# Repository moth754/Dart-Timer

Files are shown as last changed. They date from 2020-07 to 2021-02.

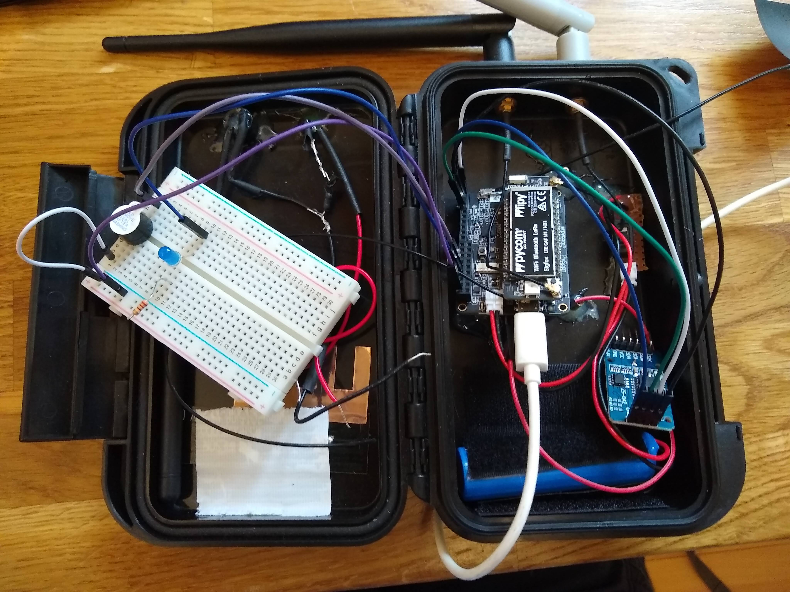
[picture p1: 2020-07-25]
Instructions/Images/Proof of concept.jpg

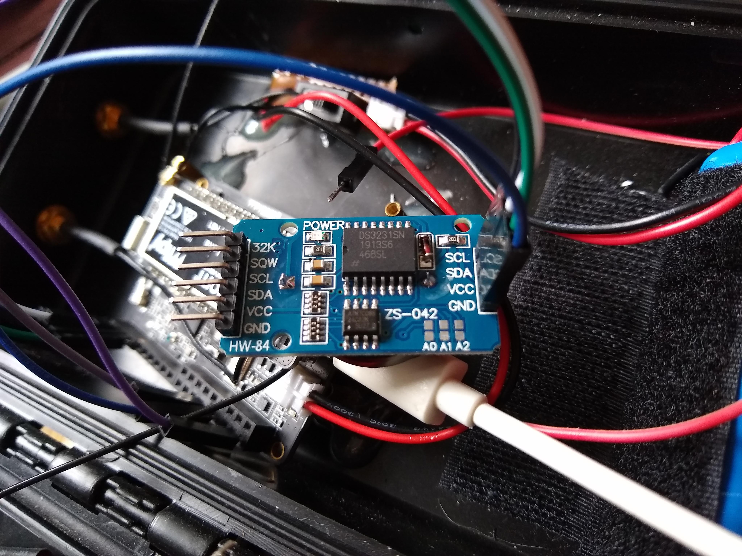
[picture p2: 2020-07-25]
Instructions/Images/RTC.jpg

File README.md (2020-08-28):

# Dart-Timer
This is a timing system built using micropython and based on a [Pycom](https://pycom.io/) FiPy board (will work with some other pycom boards).

The system records taps via NFC chips and relays the chip ID and the time of the tap to a Google Sheet. This can then be analysed to produce timing results.

The system makes use of Pycom's [Pybytes](https://pycom.io/products/software/pybytes-3/) as an easy way to manage the devices and recieve the data. The Pybytes software then sends the data on to the Google Sheet via HTTP post.

Obviously you will need a stock of NFC chips to make this work, but these are freely available - just check it's compatible with a MFRC630. 

Why is this different to other timing systems?
- Others can build, use and develop for free
- Uses Google Sheets so no additional specialist software is required and permissions can be managed easily (so a cut down view can shared with the public live during the race, marshals can see how many are on the course at a glance etc)
- Low running costs (no ongoing license fee for the software or hardware)
- Uses technology such as LoRa and NB-IOT to provide live data even in areas with poor mobile connectivity
- Relatively low cost per checkpoint in comparison to other live data feed systems
- Low cost and re-usable competitor devices (a simple wrist worn NFC tag)

##### Go Fund Me link for the next stage of development - https://gf.me/u/yiimtw

## Important code information
You need to run the following code via REPL to disable pybytes autostart. If you don't do this you will experience slowdowns due to mutliple threads connecting to the network. It will survive reboots.

```python
import pycom
pycom.pybytes_on_boot(False)
```

## Features
### Working and tested
* Records taps by NFC chips to local SD and send to Google Sheet
* Competitor numbers, names distances etc are all held in Google Sheets, so permissions and changes are straight-forward
* Visual and audible indication of successful tap by competitor
* Can use wifi, LoRa ([The Things Network](https://www.thethingsnetwork.org/)) and NB-IOT (a low power, long range cellular network) to connect to the internet
* Device design encloses the entire project in a small waterproof case
* Real time clock which can be updated via NTP via using a particular NFC card (set in code)

### Probably working but needs more testing
* 24 hour battery life
* Devices can mesh network to reduce the chances of connectivity outage - see [Pycom's](https://pycom.io/launching-mesh-networks/) page on mesh networking for more info

### Upcoming
The "to do" list can be found [here](https://trello.com/b/PtuwPh5d/timing-system) on Trello

## Instructions
Build instructions can be found in the instructions folder [here](https://github.com/moth754/Dart-Timer/blob/master/Instructions/INSTRUCTIONS.md).

# The Story
For a couple of years I have marshalled and timed various events. These have mostly been trail running, with a bit of swim running added in for good measure. On the higher risk ultra events timing was done by GPS trackers, but for the rest either NFC (webscorer or SiE) or RFID timing was used.

The most commonly asked question by far when I've been timing events has been by friends and family of the competitors "can you see where they are?" The answer is usually no. Interim timing points require additional kit and extra personnel, both f which are a luxery not normally available for the small to medium scale events. When splits timing is required we often hire the superb SiE system forn another local organiser. Several of our events do have a few splits!

Water safety teams would ask how many in and out the water for different swimrun stages, which the marshals on those checkpoints can usually provide. until they get distracted from counting to deal with first aid issues etc. 

To answer both the issue of people wanting to know where thier loved ones are on a route, and the safety issues, this timing system has come about. On the surface it is a very simple concept. Record who scans it at what time. However, it have taken a year of experimentation (on and off), and near giving up to get this far.

It's available to all (see license) as although it is a fairly technical know how heavy solution, for some race organisers and race timers it may prove useful.

## Thanks
Thanks the the following sources whom I have used thier code (in accordance with licenses) to make this project possible. 

* DS3231 code from the [MicroPython Chinese Community](https://github.com/micropython-Chinese-Community/mpy-lib/tree/master/misc/DS3231)
* This [post](https://railsrescue.com/blog/2015-05-28-step-by-step-setup-to-send-form-data-to-google-sheets/) by Scott Olmsted on posting to Google Sheets
* Pycom support who have been amazing solving problems (largely created by me)
* The PCA9554 library by akael "ported" by theshade
* Everyone elses various posts on forums etc I read in the making of this!

Special thanks to-
 * Laura (https://www.runventureonline.com/)
 * Ceri (https://www.wildrunning.co.uk/)
 * Ben (https://www.lasportiva.com/en)

All three are runners (with running related buisnesses) and have spurred me on to complete this project, even when I was ready to give up.

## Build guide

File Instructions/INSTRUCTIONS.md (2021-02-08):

##This is all going to change - I am switching hardware to use a custom PCB for interconnecting the modules and a Adafruit PN532 NFC reader for increased range. The end product should be significantly more robust.

# Instructions
These are the instructions to build the device how I did. It is possible to modify / change components and still end up with a working result.

## Google Sheets Instuctions
These are based on the instructions found [here](https://railsrescue.com/blog/2015-05-28-step-by-step-setup-to-send-form-data-to-google-sheets/).

1. Start a new sheet and save it in Google Docs. Add the columns names "device" and "payload"
2. Click on Tools - Script Editor
3. Click on File - New Script File
4. Paste in the code from GoogleIntegrations.gs (top level in this repository)
5. Click "Run"
6. Click on Publish - Deploy as web app
7. Make a note of the URL
8. Integration should be set to "Me"
9. Who has access should be set to "Anyone, even anonymous"
10. Click Deploy / Update

## Webhook Instructions
1. Setup a signal as "SIG 1", "taps" in the pybytes signals section
2. Setup a webhook integration under Pybytes integrations section. The correct configuration is shown in the Pybytes Webhook image
3. The URL is the "current web app URL" from the Google Sheets setup

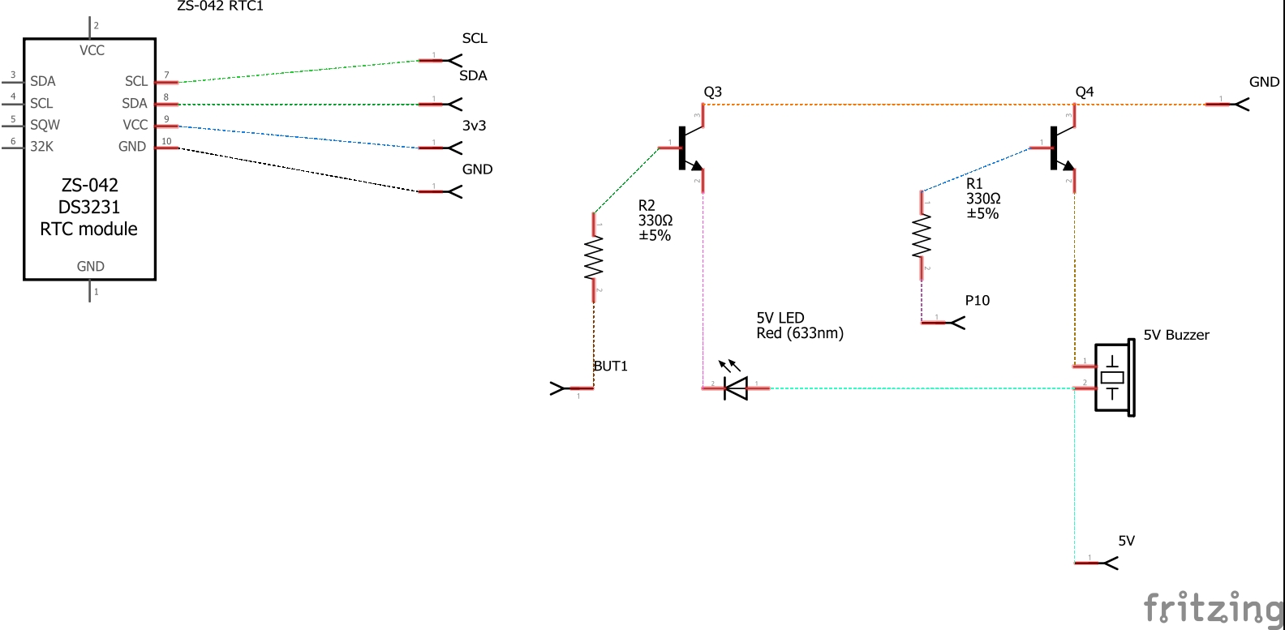
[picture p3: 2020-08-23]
Instructions/Images/Wiring diagram_schem.jpg

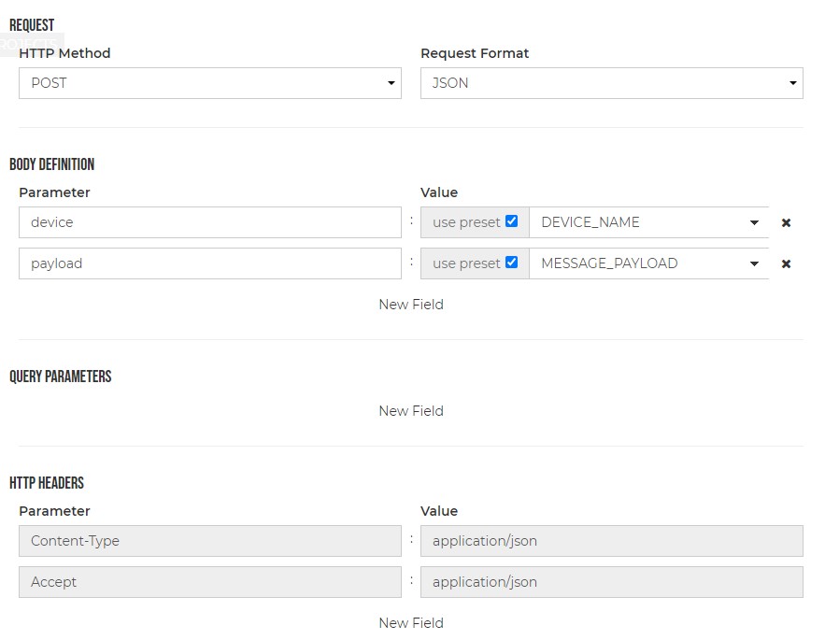
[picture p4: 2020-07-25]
Instructions/Images/Pybytes Webhook.jpg

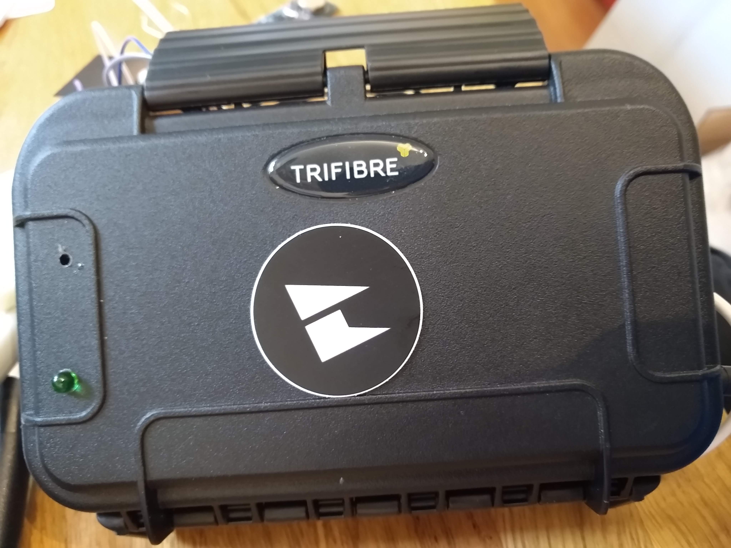
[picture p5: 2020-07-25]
Instructions/Images/Front.jpg

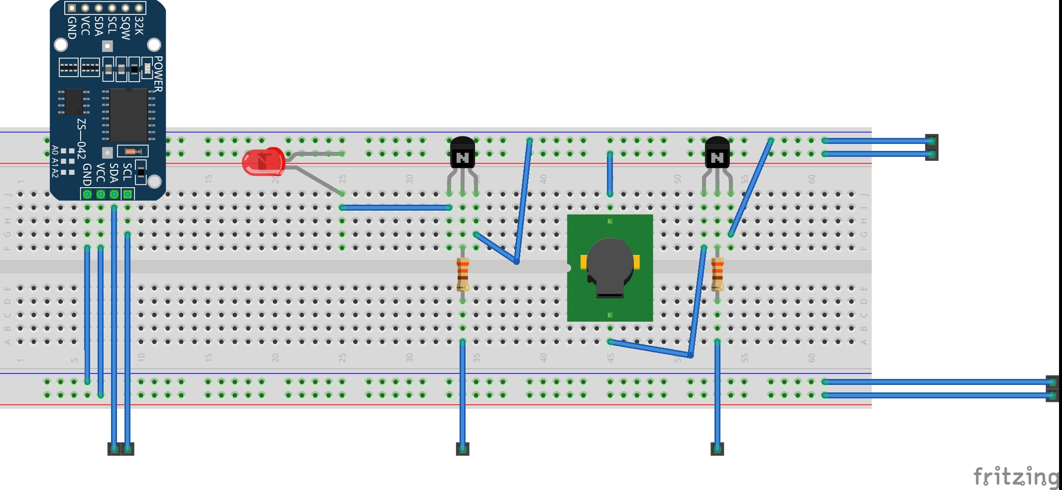
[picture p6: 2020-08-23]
Instructions/Images/Wiring diagram_bb.jpg

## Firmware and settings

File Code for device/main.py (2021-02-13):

################### imports

#print("Starting imports")

from pyscan import Pyscan
from MFRC630 import MFRC630
import time
import pycom
from machine import SD, I2C, RTC, Pin, ADC
from pca9554 import PCA9554 #for io expander
import _thread
import os
import DS3231 #for RTC
import gc
import ubinascii

#imports for pybytes if doing manual on and off or reading
#from _pybytes_config import PybytesConfig
#from _pybytes import Pybytes
#pybytes_config = PybytesConfig().read_config()
#pybytes = Pybytes(pybytes_config)

#import for watchdog
from machine import WDT

#####################setups

#pymesh
pymesh = pybytes.__pymesh.__pymesh
#pymesh.status_str() whole status string - we want character 5

#setup SD card
sd = SD()
os.mount(sd, "/sd")

#setup buzzer using Pin
buzzer = Pin('P11', mode=Pin.OUT)
#tests buzzer using pin
buzzer(True)
time.sleep(1)
buzzer(False)

#setup LEDs using IO expander
led = PCA9554(line=1, direction=0)
#tests LED using IO expander
led.set()
time.sleep(1)
led.reset()

#clock setup
rtc = RTC() #internal RTC module
i2c = I2C(0, pins=('P22','P21')) #setup i2c interface
ds = DS3231.DS3231(i2c) #establish connection to i2c clock

#setup taps pending list and counter
taps_pending = []
count = 0

#setup scan
py = Pyscan()
nfc = MFRC630(py)
nfc.mfrc630_cmd_init() # Initialise the MFRC630 with some settings

#setup thread lock
sendlock = _thread.allocate_lock()

################# Functions start

def chiplog(tap): #local recording of taps as csv on sd card
    f = open("/sd/taplog.csv", "a")
    f.write(tap)
    f.write("\n")
    f.close()

def time_calc(): #get time from external RTC
    time_now = ds.DateTime()
    year = str(time_now[0])
    month = str(time_now[1])
    day = str(time_now[2])
    weekday =str(time_now[3])
    hour = str(time_now[4])
    minute = str(time_now[5])
    second = str(time_now[6])
    if len(second) == 1:
        second = "0" + second
    if len(month) == 1:
        month = "0" + month
    if len(day) == 1:
        day = "0" + day
    if len(hour) == 1:
        hour = "0" + hour
    if len(minute) == 1:
        minute = "0" + minute

    #millisecond = str(time_now[7])
    time_stamp = year + "-" + month + "-" + day + " " + hour + ":" + minute + ":" + second

    #clear up
    del year
    del month
    del day
    del hour
    del minute
    del second
    del time_now

    return(time_stamp) #send the time stamp back

def minute_check(): #get last two digits - no longer used
    time_now = ds.DateTime()
    minute = str(time_now[5])
    del time_now
    if len(minute) == 1:
        minute = "0" + minute
    return(minute)

def chipscan(): #picking up the NFC chips
    # Send REQA for ISO14443A card type
    atqa = nfc.mfrc630_iso14443a_WUPA_REQA(nfc.MFRC630_ISO14443_CMD_REQA)
    if (atqa != 0):
        # A card has been detected, read UID
        uid = bytearray(11)
        uid_len = nfc.mfrc630_iso14443a_select(uid)
        #print("Detected")
        if (uid_len > 0): # A valid UID has been detected, print details
            #print("UID Detected")
            #print(uid_len)
            if uid_len == 4:
                uid = uid[:4]
            elif uid_len == 7:
                uid = uid[:7]
            elif uid_len == 8:
                uid = uid[:8]
            else:
                print("UID length max")
            #print(uid)
            uidhex = ubinascii.hexlify(uid) #turn the uid into a hex
            uidhex = uidhex.decode('UTF-8','ignore') #turn the jhex into a string
            uidhex = uidhex.upper() #upper case all letters
            print(uidhex)
            return(uidhex)
        else:
            return("misread")
    else:
        return("no_chip")
    #reset for next time
    nfc.mfrc630_cmd_reset()
    time.sleep(0.1)
    # Re-Initialise the MFRC630 with settings as these got wiped during reset
    nfc.mfrc630_cmd_init()

def posindication(): #beep and flash for successful scan
    global count
    #buzzer.set()
    buzzer(True)
    led.set()
    time.sleep(0.3)
    #buzzer.reset()
    buzzer(False)
    led.reset()
    count = 0

def negindication(): #periodic flash
    global count
    if count == 10:
        led.set()
        time.sleep(0.2)
        led.reset()
        count = 0
    else:
        count = count + 1

def setexternalrtc():
    buzzer(True)
    led.set()
    time.sleep(0.5)
    buzzer(False)
    time.sleep(0.5)
    buzzer(True)
    time.sleep(0.5)
    buzzer(False)

    #start ntp sync
    rtc.ntp_sync("0.uk.pool.ntp.org",update_period=3600) #get the time and sync microprocessor time
    time.sleep(5)
    if rtc.synced() == True:
        time_now = rtc.now()
        #set date on external RTC
        ds.Year(time_now[0])
        ds.Month(time_now[1])
        ds.Day(time_now[2])
        #set time
        ds.Hour(time_now[3])
        ds.Minute(time_now[4])
        ds.Second(time_now[5])
        #indicate on external RTC
        print("Time synced")
        buzzer(True)
        time.sleep(0.5)
        buzzer(False)
    else:
        print("Time not synced")
    led.reset()

def pymesh_check(): #checks the status of pymesh - only sends if connected
    status_check = pymesh.status_str()
    status_check = status_check[5]
    if status_check == "0":
        status_check = False
    elif status_check == "1":
        status_check = False
    else:
        status_check = True
    return(status_check)



################# SubFunctions end and main thread functions start

def mainloop(): #main loop looking for and handling UIDs from chips
    wdt = WDT(timeout=10000)  # enable watchdog with a timeout of 10 seconds
    global taps_pending
    global threadsswitch
    while True:
        uid_send = chipscan()
        if uid_send == "misread":
            negindication()
        elif uid_send == "no_chip":
            negindication()
        elif uid_send == "734D0185":
            setexternalrtc()
        else:
            tap = ("uid"+uid_send+"timestamp"+time_calc())
            chiplog(tap)
            sendlock.acquire()
            taps_pending.append(tap)
            sendlock.release()
            print(tap)
            del tap
            del uid_send
            posindication()
        wdt.feed()
        time.sleep(0.1)

def checkpending(): #checks the unsent list and sends and unsent taps
    print("Check Pending Started")
    #time.sleep(60) #not needed if not starting pybytes within main.py
    global taps_pending
    sendlock.acquire()
    poweronmsg = ("power_on_"+time_calc())
    pybytes.send_signal(3,poweronmsg)
    sendlock.release()
    del poweronmsg
    while True:
        try:
            #pybytes.isconnected()
            #minutes = minute_check()
            if pymesh_check() == True:
                sendlock.acquire()
                if len(taps_pending) > 0: #if there are taps to send, send them
                    print("Sending " + taps_pending[0])
                    pybytes.send_signal(1,taps_pending[0])
                    del taps_pending[0]
                    sendlock.release()
                    time.sleep(1)
                    #gc.collect()
                else: #there is nothing to send
                    sendlock.release()
                    #print("Sleeping with connection")
                    #pybytes.send_signal(2,"sleeping with  connection")
                    time.sleep(1)
                    #gc.collect()
            else: #no connection
                #print("Sleeping without connection")
                time.sleep(60)
                #pybytes.connect() #reconnect pybytes
                #gc.collect()
        except:
            time.sleep(5)

################# main thread functions end


#thread start and mainloop start
_thread.start_new_thread(checkpending,())
mainloop()

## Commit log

2020-07-23 LED and buzzer works. Code tidied.
    [main.py]
2020-07-23 Re-organised to allow instructions for making
    [Wiring diagram.fzz]
2020-07-25 New wiring diagram
    [Wiring diagram.fzz]
2020-08-01 Using GPIO expander due to pin clash
2020-08-03 New instructions for transistor modification
    [Wiring diagram.fzz]
2020-08-03 Added usb cable modifications
2020-08-23 Revised for 330 ohm resistors for current limiting
    [Wiring diagram.fzz]
2020-08-23 Modified for changes to pin numbers
2020-08-25 Missed a buzzer pin / GPIO extender change
    [main.py]
2020-08-31 trying to solve cell switching and LTE issues
    [main.py]
2020-10-20 Fixed shared function+ list operations thread safe
    [main.py]
2021-02-08 One thread removed from main.py as not needed
